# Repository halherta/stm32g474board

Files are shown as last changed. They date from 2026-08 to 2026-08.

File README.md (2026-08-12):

# EmbLynx

An embedded systems development board based on the **STM32G474RE** microcontroller.

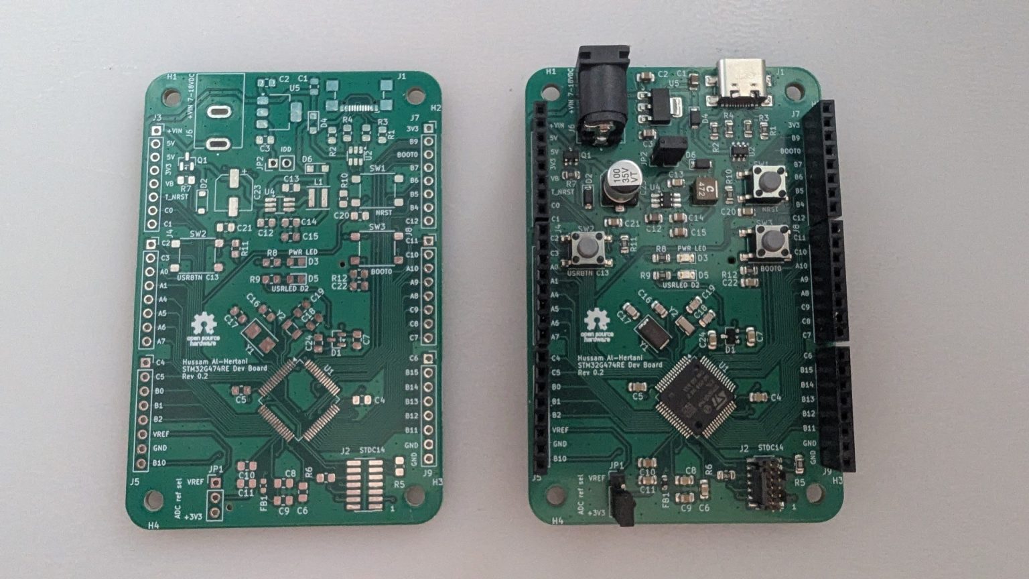
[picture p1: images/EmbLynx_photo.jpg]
EmbLynx board


EmbLynx is a compact, feature-rich development board built around ST's STM32G474RE — a mixed-signal Cortex-M4 SoC with an unusually dense analog front end (5x ADC, 7x DAC, 6x OPAMP, 7x comparator) alongside DSP/math accelerators aimed at digital power conversion, motor control, and precision sensing. The board exposes that analog and digital peripheral set on standard 0.1" headers so it can be used as a general-purpose prototyping platform or stacked with daughterboards.

Full write-up: [hussamtalkstech.com/emblynx](https://hussamtalkstech.com/emblynx/)

## Features

- **MCU:** STM32G474RE (Arm Cortex-M4F, up to 170 MHz, 512 KB Flash, 128 KB SRAM)
- **Power input:**
  - Reverse-polarity-protected DC jack or Vin pin (6–30 V), stepped down via an AP63205WU buck converter to 5 V
  - Direct 5 V input via I/O header pins or USB-C (with TVS protection and 22 Ω series resistors)
  - 3.3 V rail generated from the 5 V rail via an LDO
- **Debug:** STDC14 SWD/JTAG/serial port (STLink-V3 compatible)
- **User I/O:** RESET and BOOT0 buttons (USB DFU-friendly), user pushbutton (PC13), power LED, user LED (PD2)
- **Analog support:** Jumper-selectable Vref (+3V3 or external), filtering on VDD_A / VREF+
- **Current measurement:** IDD jumper (JP2) isolates the microcontroller's own 3.3 V rail (+3V3) from the peripheral/LED rail (+3V30) for clean current measurements
- **RTC backup:** BAT54C dual-Schottky arrangement feeds VBAT from either a coin-cell on the I/O header or +3V3 when no battery is present
- **Form factor:** 2.2" x 3.3", 4-layer PCB, 6x 8-pin 0.1" I/O headers (stacking-header compatible)

## STM32G474RE peripheral highlights

| Category | Details |
|---|---|
| Core | Cortex-M4F w/ FPU + DSP, 170 MHz, ART Accelerator, 0-wait-state Flash |
| Memory | 512 KB dual-bank Flash (ECC), 128 KB SRAM (parity on select blocks), 32 KB CCM-SRAM |
| Math accelerators | CORDIC (trig/hyperbolic), FMAC (FIR/IIR/3p3z filters) |
| Timers | 17 total, incl. HRTIM (184 ps resolution), motor-control timers, watchdogs |
| Connectivity | 3x FDCAN, 4x I2C (Fast-mode+), 5x USART/UART, 1x LPUART, 4x SPI/2x I2S, SAI, USB 2.0 FS, USB-C/UCPD |
| ADC | 5x independent 12-bit SAR, up to 4 Msps each (8 Msps interleaved), up to 16-bit via oversampling |
| DAC | 7 channels (3 buffered external @ 1 Msps, 4 unbuffered internal @ 15 Msps) |
| OPAMP | 6x, externally accessible, configurable as PGAs (x2–x64), ~13 MHz bandwidth |
| Comparator | 7x, 16.7 ns propagation delay, programmable hysteresis |
| Reference | VREFBUF with 2.048 V / 2.5 V / 2.95 V presets |
| Other | 16-channel DMA, FSMC/Quad-SPI, hardware RNG, CRC, internal temp sensor |

## Getting started

### Prerequisites

- [KiCad](https://www.kicad.org/) 7.x or later

### Opening the project

1. Clone this repository:
   ```bash
   git clone https://github.com/halherta/stm32g474board.git
   ```
2. Open `stm32g474board.kicad_pro` in KiCad.

### Schematic

EmbLynx board schematic

A rendered PDF of the full schematic is included [here](https://github.com/halherta/stm32g474board/blob/main/stm32g474board.pdf).

### Layout

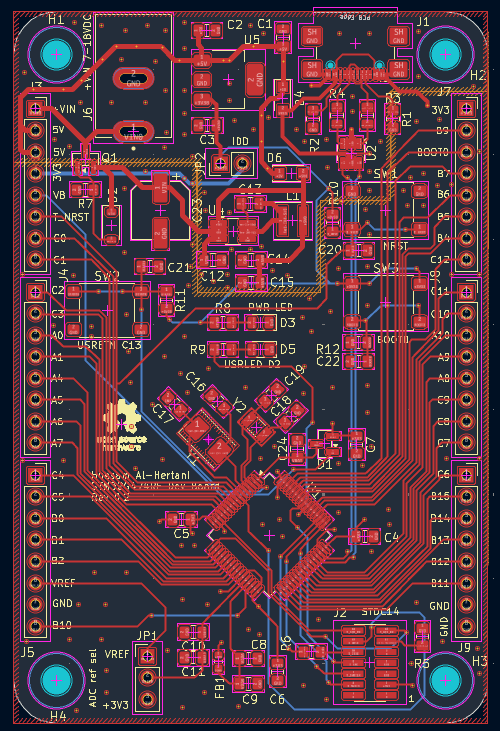
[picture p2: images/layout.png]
EmbLynx board layout


### Parts Library

my latest Kicad footprint / symbol parts library cab always be found [here](https://github.com/halherta/mykicadlibrary)

## Power architecture

| Rail | Source | Notes |
|---|---|---|
| VIN (6–30 V) | DC jack or I/O header | Reverse-polarity protected |
| +5V | VIN → AP63205WU buck, or direct 5 V pin, or USB-C | USB-C input has TVS + 22 Ω series protection |
| +3V30 | +5V → LDO | Powers LEDs, pull-ups, always-on peripherals |
| +3V3 | +3V30 → IDD jumper (JP2) | Powers the MCU only; JP2 allows current measurement of the MCU in isolation |
| VBAT | Coin cell (I/O header) or +3V3 | Selected via BAT54C dual-Schottky diodes |

## Credits

Designed by [Hussam](https://hussamtalkstech.com/about) — [hussamtalkstech.com](https://hussamtalkstech.com/)

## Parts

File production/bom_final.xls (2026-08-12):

Comment | Designator | Footprint | JLCPCB Part # | Qty | Ext.Price($)
AP63205WU | U4 | TSOT-23-6_HandSoldering | C2071056 | 2 | 0.87
USBLC6-2SC6 | U2 | SOT-23-6 | C2827654 | 6 | 0.25
1u | C10,C2,C9 | 0805 | C28323 | 6 | 0.11
22u | C14,C15 | 0805 | C45783 | 4 | 0.25
4.7u | L1 | L_Coilcraft_XxL4040 | C19191688 | 2 | 4.28
Barrel_Jack | J6 | CUI_PJ-037AH | C3095395 | 2 | 2.47
8MHz | Y1 | Crystal_SMD_5032-2Pin_5.0x3.2mm | C144380 | 2 | 1.15
4.7u | C3 | 0805 | C76642 | 6 | 0.47
MMSZ52XXB | D2 | D_SOD-123 | C21564 | 15 | 0.38
22 | R3,R4 | 0805 | C17561 | 4 | 0.01
PMEG3010BER | D4,D6 | Nexperia_CFP3_SOD-123W | C552860 | 4 | 0.87
LED | D3,D5 | 0805 | C84256 | 4 | 0.05
100k | R7 | 0805 | C149504 | 2 | 0.01
100u | C23 | CP_Elec_6.3x7.7 | C970686 | 5 | 0.19
AO3401A | Q1 | SOT-23 | C15127 | 2 | 0.13
47 | R6 | 0805 | C17714 | 2 | 0.00
adcrefsel | JP1 | PinHeader_1x03_P2.54mm_Vertical | C49257 | 4 | 0.10
100 | R5 | 0805 | C17408 | 2 | 0.00
5.1k | R1,R2 | 0805 | C27834 | 4 | 0.01
IDD | JP2 | PinHeader_1x02_P2.54mm_Vertical | C42431681 | 4 | 0.06
10n | C11 | 0805 | C1710 | 2 | 0.02
27p | C16,C17 | 0805 | C1808 | 20 | 0.14
10k | R10,R11,R12 | 0805 | C17414 | 6 | 0.02
32K | Y2 | Crystal_SMD_3215-2Pin_3.2x1.5mm | C156245 | 5 | 1.34
7p | C18,C19 | 0805 | C1836 | 20 | 0.11
SW_Push | SW1,SW2,SW3 | SW_SPST_PTS645Sx43SMTR92 | C221869 | 6 | 2.56
STM32G474RETx | U1 | LQFP-64_10x10mm_P0.5mm | C521608 | 2 | 12.34
0.1u | C13,C20,C21,C22,C24,C4,C5,C6,C7,C8 | 0805 | C49678 | 20 | 0.15
BAT54C | D1 | SOT-23 | C22466350 | 10 | 0.14
USB_C_Receptacle_USB2.0_16P | J1 | USB_C_Receptacle_GCT_USB4110 | C5143397 | 2 | 3.30
600@100MHz | FB1 | 0603 | C1002 | 2 | 0.04
10u | C1,C12 | 0805 | C237493 | 6 | 1.06
Left_top | J8,J5,J4,J9,J7,J3 | PinSocket_1x08_P2.54mm_Vertical | C7509515 | 12 | 1.16
AP7361C-33E | U5 | SOT-223-3_TabPin2 | C500795 | 5 | 2.90
330 | R8,R9 | 0805 | C17630 | 4 | 0.01
Conn_ST_STDC14 | J2 | PinHeader_2x07_P1.27mm_Vertical_SMD | C5307809 | 2 | 5.47

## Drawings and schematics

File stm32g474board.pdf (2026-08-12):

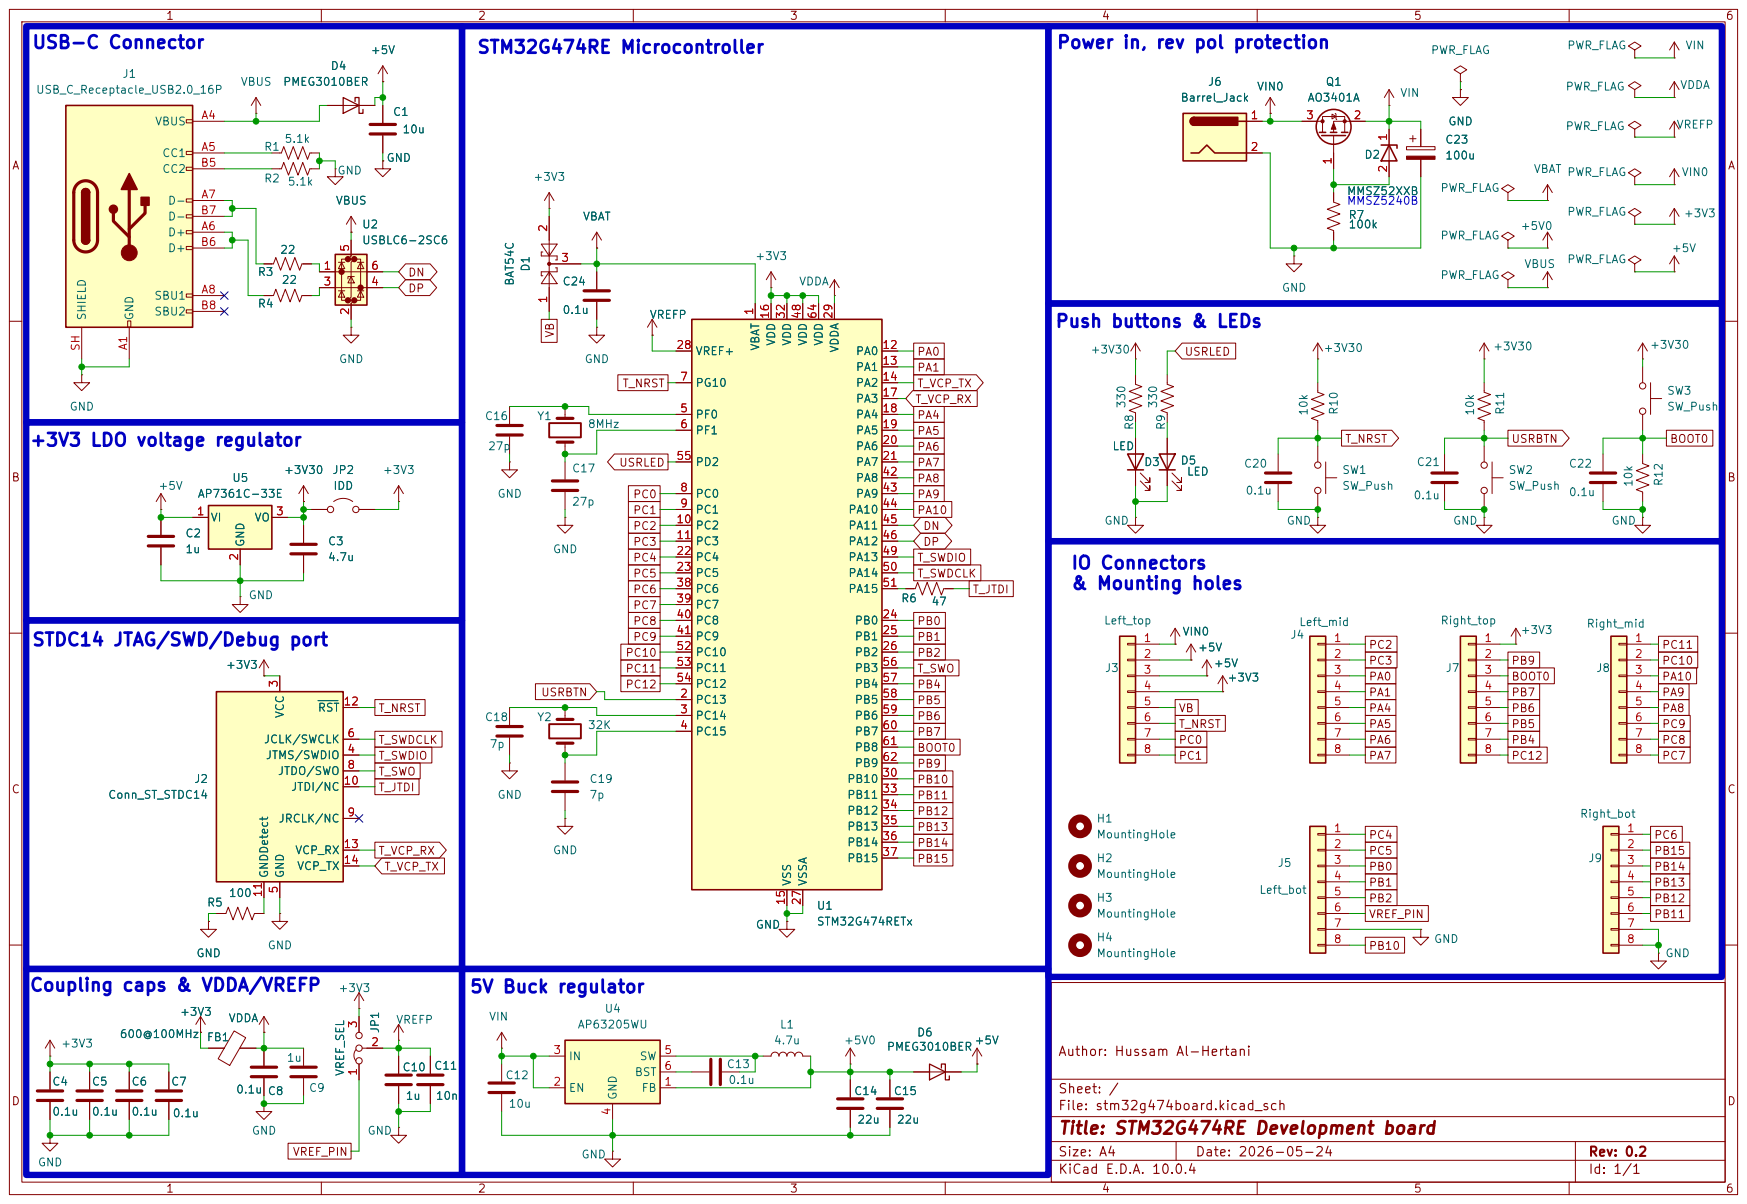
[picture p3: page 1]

USB-C Connector | | VBUS PWR_FLAG

SBU2 | B8 SHIELD SH

STDC14 JTAG/SWD/Debug port GND GND

Coupling caps & VDDA/VREFP | 5V Buck regulator VIN AP63205WU

Size: A4 | Rev: 0.2
KiCad E.D.A. 10.0.4 | Id: 1/1

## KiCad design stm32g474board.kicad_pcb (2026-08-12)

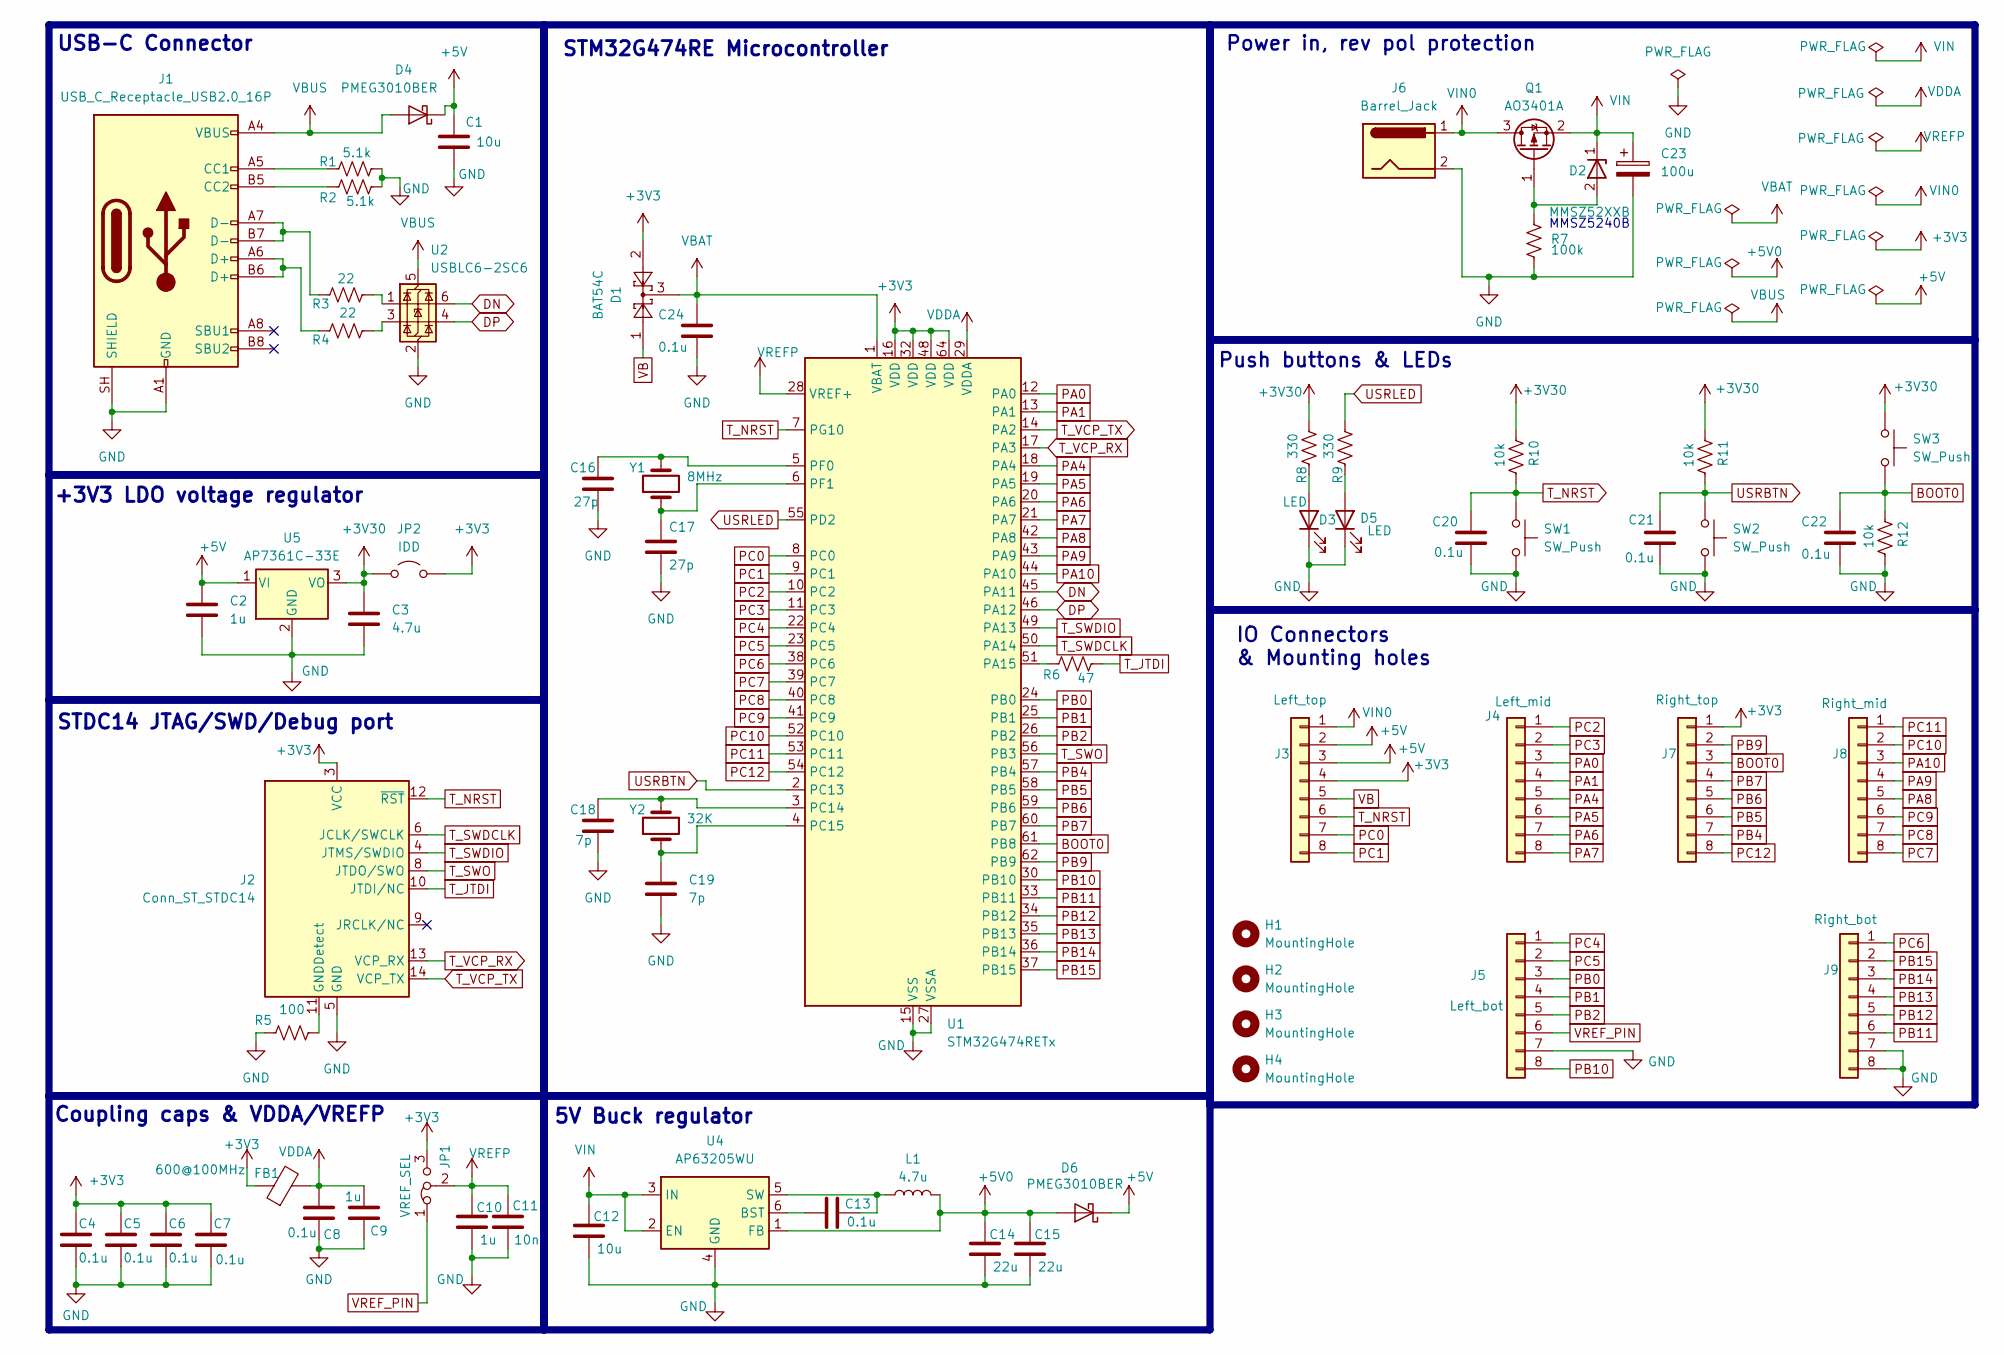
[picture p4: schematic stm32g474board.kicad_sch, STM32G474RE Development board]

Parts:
C1, C12: 10u; C_0805_2012Metric_Pad1.18x1.45mm_HandSolder
C2, C9, C10: 1u; C_0805_2012Metric_Pad1.18x1.45mm_HandSolder
C3: 4.7u; C_0805_2012Metric_Pad1.18x1.45mm_HandSolder
C4, C5, C6, C7, C8, C13, C20, C21, C22, C24: 0.1u; C_0805_2012Metric_Pad1.18x1.45mm_HandSolder
C11: 10n; C_0805_2012Metric_Pad1.18x1.45mm_HandSolder
C14, C15: 22u; C_0805_2012Metric_Pad1.18x1.45mm_HandSolder
C16, C17: 27p; C_0805_2012Metric_Pad1.18x1.45mm_HandSolder
C18, C19: 7p; C_0805_2012Metric_Pad1.18x1.45mm_HandSolder
C23: 100u; CP_Elec_6.3x7.7
D1: BAT54C; SOT-23
D2: MMSZ52XXB; D_SOD-123
D3, D5: LED; LED_0805_2012Metric_Pad1.15x1.40mm_HandSolder
D4, D6: PMEG3010BER; Nexperia_CFP3_SOD-123W
FB1: 600@100MHz; L_0603_1608Metric
H1, H2, H3, H4: MountingHole; MountingHole_3.2mm_M3
J1: USB_C_Receptacle_USB2.0_16P; USB_C_Receptacle_GCT_USB4110
J2: Conn_ST_STDC14; PinHeader_2x07_P1.27mm_Vertical_SMD
J3: Left_top; PinSocket_1x08_P2.54mm_Vertical
J4: Left_mid; PinSocket_1x08_P2.54mm_Vertical
J5: Left_bot; PinSocket_1x08_P2.54mm_Vertical
J6: Barrel_Jack; CUI_PJ-037AH
J7: Right_top; PinSocket_1x08_P2.54mm_Vertical
J8: Right_mid; PinSocket_1x08_P2.54mm_Vertical
J9: Right_bot; PinSocket_1x08_P2.54mm_Vertical
JP1: VREF_SEL; PinHeader_1x03_P2.54mm_Vertical
JP2: IDD; PinHeader_1x02_P2.54mm_Vertical
L1: 4.7u; L_Coilcraft_XxL4040
Q1: AO3401A; SOT-23
R1, R2: 5.1k; R_0805_2012Metric_Pad1.20x1.40mm_HandSolder
R3, R4: 22; R_0805_2012Metric_Pad1.20x1.40mm_HandSolder
R5: 100; R_0805_2012Metric_Pad1.20x1.40mm_HandSolder
R6: 47; R_0805_2012Metric_Pad1.20x1.40mm_HandSolder
R7: 100k; R_0805_2012Metric_Pad1.20x1.40mm_HandSolder
R8, R9: 330; R_0805_2012Metric_Pad1.20x1.40mm_HandSolder
R10, R11, R12: 10k; R_0805_2012Metric_Pad1.20x1.40mm_HandSolder
SW1, SW2, SW3: SW_Push; SW_SPST_PTS645Sx43SMTR92
U1: STM32G474RETx; LQFP-64_10x10mm_P0.5mm
U2: USBLC6-2SC6; SOT-23-6
U4: AP63205WU; TSOT-23-6_HandSoldering
U5: AP7361C-33E; SOT-223-3_TabPin2
Y1: 8MHz; Crystal_SMD_5032-2Pin_5.0x3.2mm
Y2: 32K; Crystal_SMD_3215-2Pin_3.2x1.5mm

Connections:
+3V3: C4.1, C5.1, C6.1, C7.1, D1.2, FB1.1, J2.3 (VCC), J3.4, J7.1, JP1.3 (B), JP2.2 (B), U1.16 (VDD), U1.32 (VDD), U1.48 (VDD), U1.64 (VDD)
+3V30: C3.1, JP2.1 (A), R8.2, R10.2, R11.2, SW3.1, U5.3 (VO)
+5V: C1.1, C2.1, D4.1 (K), D6.1 (K), J3.2, J3.3, U5.1 (VI)
+5V0: C14.1, C15.1, D6.2 (A), L1.2, U4.1 (FB)
BOOT0: C22.1, J7.3, R12.2, SW3.2, U1.61 (PB8)
DN: U1.45 (PA11), U2.6 (I/O1)
DP: U1.46 (PA12), U2.4 (I/O2)
GND: C1.2, C2.2, C3.2, C4.2, C5.2, C6.2, C7.2, C8.2, C9.2, C10.2, C11.2, C12.2, C14.2, C15.2, C16.2, C17.2, C18.2, C19.2, C20.2, C21.2, C22.2, C23.2, C24.2, D3.1 (K), D5.1 (K), J1.A1 (GND), J1.A12 (GND), J1.B1 (GND), J1.B12 (GND), J1.SH (SHIELD), J2.5 (GND), J2.7 (GND), J5.7, J6.2, J9.7, J9.8, R1.2, R2.2, R5.1, R7.2, R12.1, SW1.2, SW2.2, U1.15 (VSS), U1.27 (VSSA), U1.31 (VSS), U1.47 (VSS), U1.63 (VSS), U2.2 (GND), U4.4 (GND), U5.2 (GND)
unnamed: D2.2 (A), Q1.1 (G), R7.1
unnamed: D3.2 (A), R8.1
unnamed: D5.2 (A), R9.1
unnamed: J1.A5 (CC1), R1.1
unnamed: J1.B5 (CC2), R2.1
unnamed: J1.A6 (D+), J1.B6 (D+), R4.1
unnamed: J1.A7 (D-), J1.B7 (D-), R3.1
unnamed: J2.11 (GNDDetect), R5.2
unnamed: R3.2, U2.1 (I/O1)
unnamed: R4.2, U2.3 (I/O2)
unnamed: R6.1, U1.51 (PA15)
unnamed: C18.1, U1.3 (PC14), Y2.2
unnamed: C19.1, U1.4 (PC15), Y2.1
unnamed: C16.1, U1.5 (PF0), Y1.2
unnamed: C17.1, U1.6 (PF1), Y1.1
unnamed: C13.1, U4.6 (BST)
unnamed: C13.2, L1.1, U4.5 (SW)
PA0: J4.3, U1.12 (PA0)
PA1: J4.4, U1.13 (PA1)
PA4: J4.5, U1.18 (PA4)
PA5: J4.6, U1.19 (PA5)
PA6: J4.7, U1.20 (PA6)
PA7: J4.8, U1.21 (PA7)
PA8: J8.5, U1.42 (PA8)
PA9: J8.4, U1.43 (PA9)
PA10: J8.3, U1.44 (PA10)
PB0: J5.3, U1.24 (PB0)
PB1: J5.4, U1.25 (PB1)
PB2: J5.5, U1.26 (PB2)
PB4: J7.7, U1.57 (PB4)
PB5: J7.6, U1.58 (PB5)
PB6: J7.5, U1.59 (PB6)
PB7: J7.4, U1.60 (PB7)
PB9: J7.2, U1.62 (PB9)
PB10: J5.8, U1.30 (PB10)
PB11: J9.6, U1.33 (PB11)
PB12: J9.5, U1.34 (PB12)
PB13: J9.4, U1.35 (PB13)
PB14: J9.3, U1.36 (PB14)
PB15: J9.2, U1.37 (PB15)
PC0: J3.7, U1.8 (PC0)
PC1: J3.8, U1.9 (PC1)
PC2: J4.1, U1.10 (PC2)
PC3: J4.2, U1.11 (PC3)
PC4: J5.1, U1.22 (PC4)
PC5: J5.2, U1.23 (PC5)
PC6: J9.1, U1.38 (PC6)
PC7: J8.8, U1.39 (PC7)
PC8: J8.7, U1.40 (PC8)
PC9: J8.6, U1.41 (PC9)
PC10: J8.2, U1.52 (PC10)
PC11: J8.1, U1.53 (PC11)
PC12: J7.8, U1.54 (PC12)
T_JTDI: J2.10 (JTDI/NC), R6.2
T_NRST: C20.1, J2.12 (~RST), J3.6, R10.1, SW1.1, U1.7 (PG10)
T_SWDCLK: J2.6 (JCLK/SWCLK), U1.50 (PA14)
T_SWDIO: J2.4 (JTMS/SWDIO), U1.49 (PA13)
T_SWO: J2.8 (JTDO/SWO), U1.56 (PB3)
T_VCP_RX: J2.13 (VCP_RX), U1.17 (PA3)
T_VCP_TX: J2.14 (VCP_TX), U1.14 (PA2)
USRBTN: C21.1, R11.1, SW2.1, U1.2 (PC13)
USRLED: R9.2, U1.55 (PD2)
VB: D1.1, J3.5
VBAT: C24.1, D1.3, U1.1 (VBAT)
VBUS: D4.2 (A), J1.A4 (VBUS), J1.A9 (VBUS), J1.B4 (VBUS), J1.B9 (VBUS), U2.5 (VBUS)
VDDA: C8.1, C9.1, FB1.2, U1.29 (VDDA)
VIN: C12.1, C23.1, D2.1 (K), Q1.2 (S), U4.2 (EN), U4.3 (IN)
VIN0: J3.1, J6.1, Q1.3 (D)
VREFP: C10.1, C11.1, JP1.2 (C), U1.28 (VREF+)
VREF_PIN: J5.6, JP1.1 (A)

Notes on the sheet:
Coupling caps & VDDA/VREFP
STM32G474RE Microcontroller
5V Buck regulator
Push buttons & LEDs
USB-C Connector
IO Connectors & Mounting holes
MMSZ5240B
+3V3 LDO voltage regulator
Power in, rev pol protection
STDC14 JTAG/SWD/Debug port

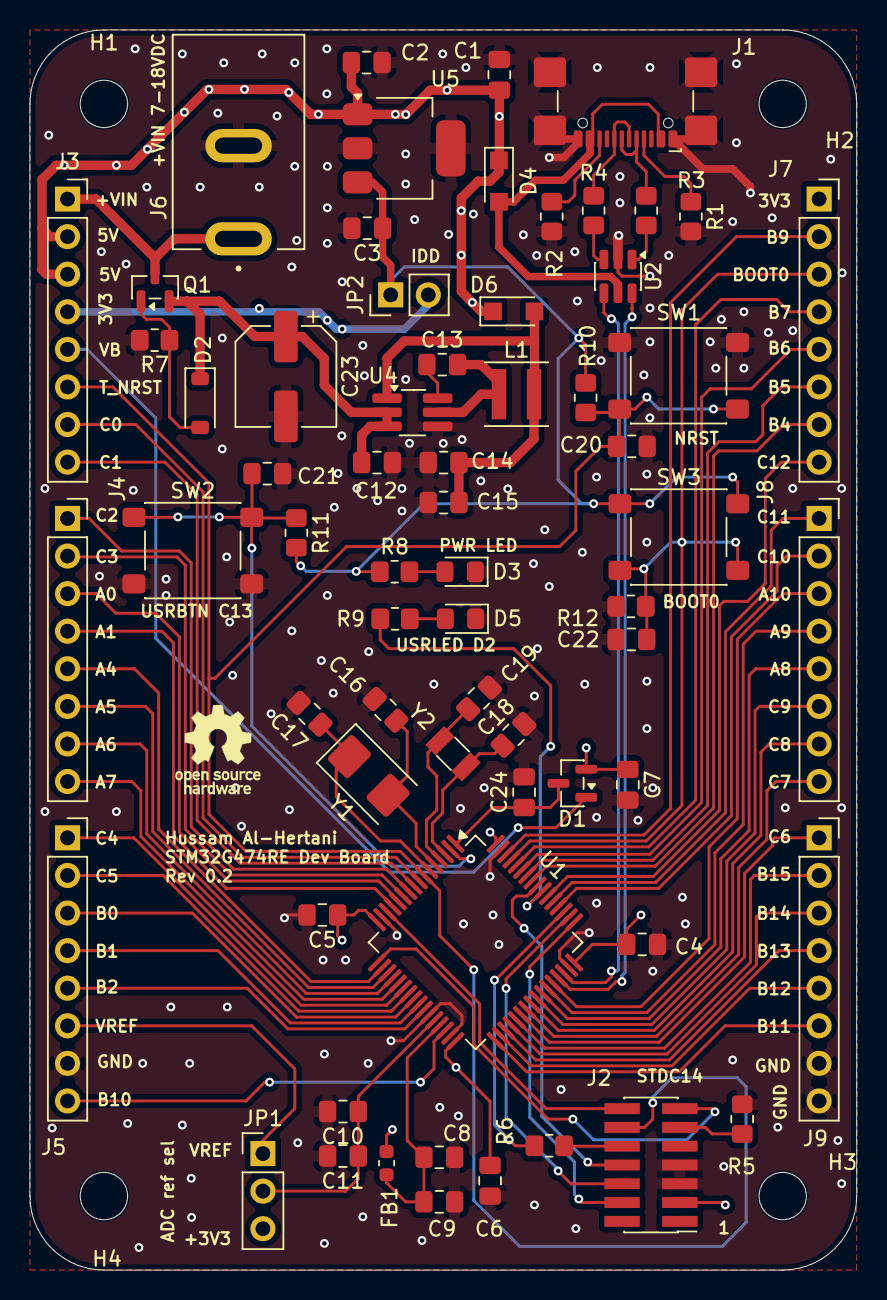
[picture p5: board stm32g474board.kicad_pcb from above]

Board: 4 copper layers, 55.9 x 83.8 mm, 69 parts (0 on the bottom side), 78 nets.
